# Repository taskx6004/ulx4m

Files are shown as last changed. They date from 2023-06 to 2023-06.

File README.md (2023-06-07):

<!--
SPDX-FileCopyrightText: 2016 2016 Goran Mahovlic, <goran.mahovlic@gmail.com> et al.

SPDX-License-Identifier: CERN-OHL-S-2.0
-->

# ULX4M-LS PCB

[ULX4M] = University digital Logic Learning Xtensible board release 4 Moduler successor of [ULX3S](http://radiona.org/ulx3s) = [University digital Logic](https://www.fer.unizg.hr/en/course/diglog) Learning
Xtensible board release 3 with SDRAM,
Successor of [ULX2S](http://github.com/emard/ulx2s).

### 3D preview

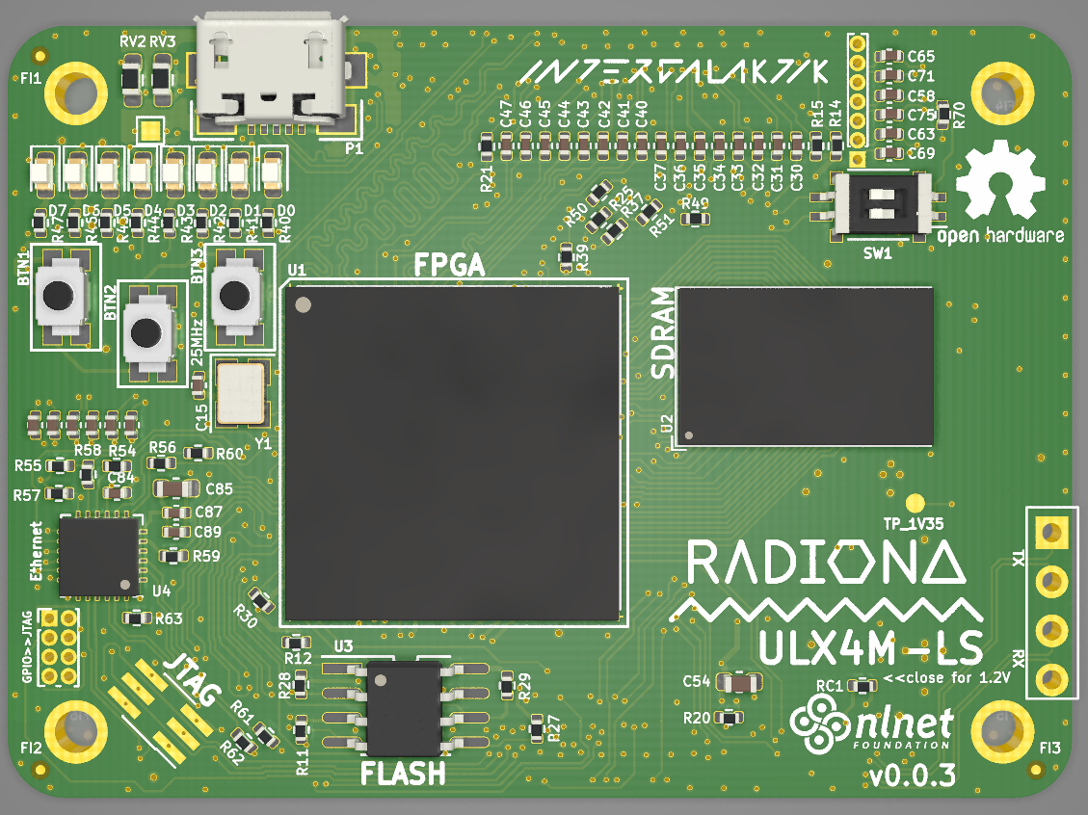
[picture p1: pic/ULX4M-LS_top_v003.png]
TOP

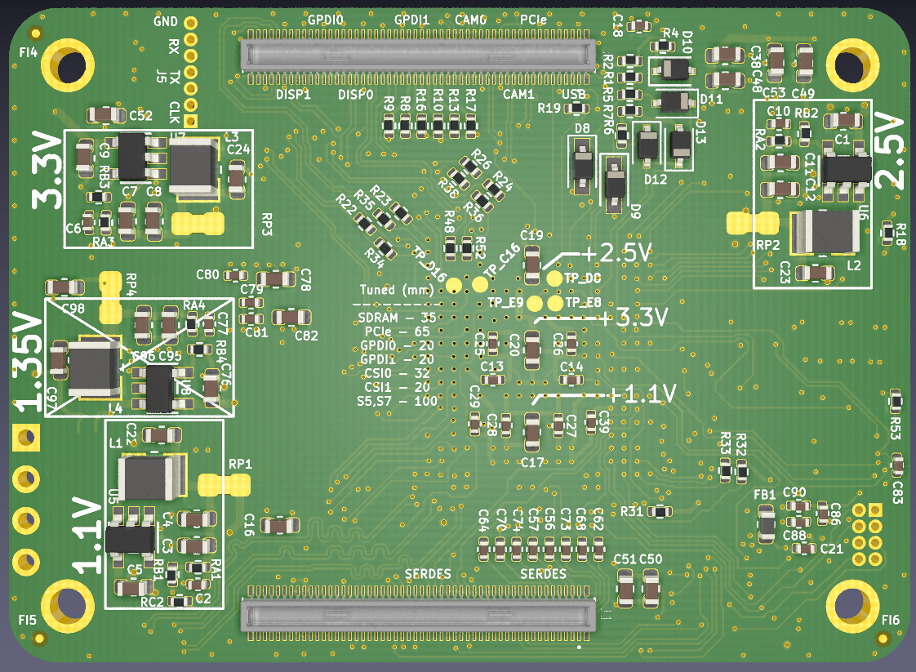
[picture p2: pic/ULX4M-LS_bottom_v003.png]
BOTTOM

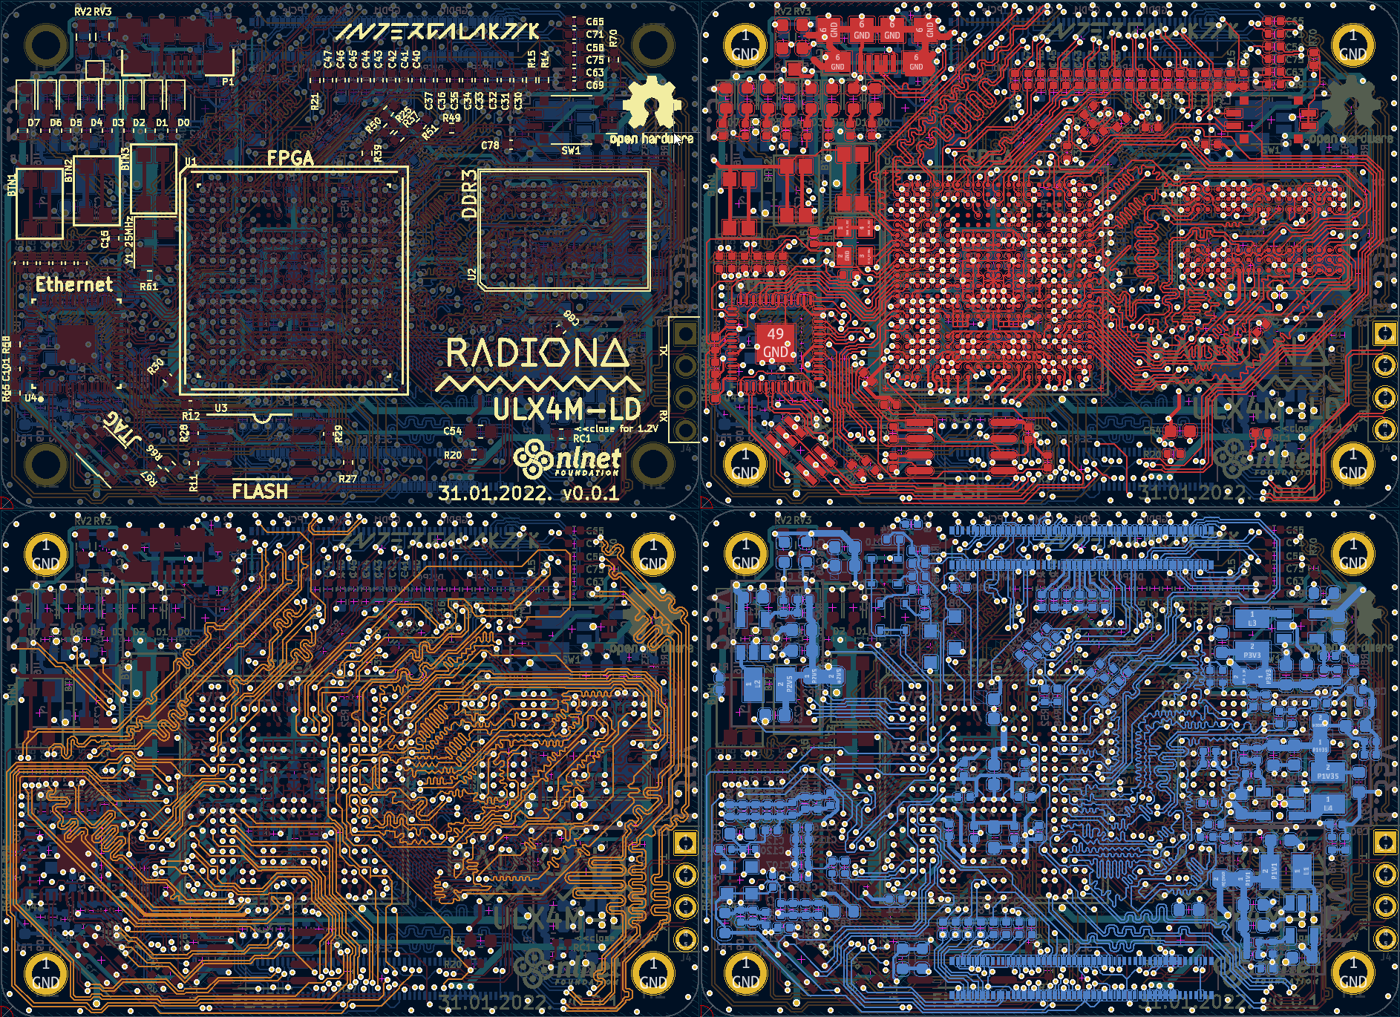
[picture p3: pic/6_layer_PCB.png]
Layers_v001


### Panel

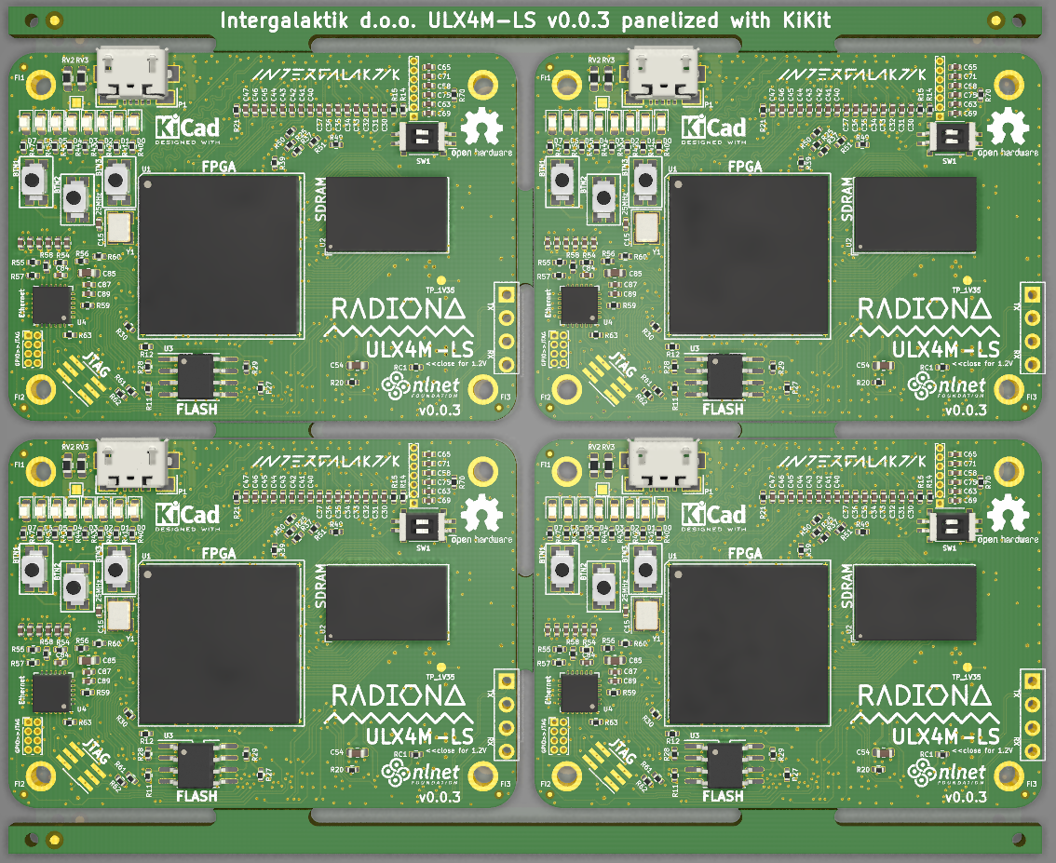
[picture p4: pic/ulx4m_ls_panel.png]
Panel


[Schematics](/doc/schematics.pdf) and PCB KiCAD 5 PCB editor:

    kicad ulx4m.pro

## Features

FPGA: Lattice ECP5 [LFE5U-12F-6BG381C](http://www.latticesemi.com/~/media/LatticeSemi/Documents/DataSheets/ECP5/FPGA-DS-02012.pdf?document_id=50461) (12/25/45/85K LUT)

### Main parts

LFE5U-12F-6BG381C

IS42S16160G-7BL 32 MB SDRAM 

W25Q128JVSIM NOR Flash spiFlash, 3V, 128M-bit, 4Kb Uniform Sector

Ethernet - LAN8720A

### Programming options

External JTAG programming connector

JTAG connected to GPIO (programming with FTDI or ESP32)

USB (bootloader)

### Periferals

- [x] 2 lane CSI camera port  CAM0 and CAM1

- [x] 2 lane DSI display port DISP0 (fake differential)

- [x] DISP0 pins connected to DISP1

- [x] * SerDes pair (TX/RX) connected to 2.0 header (radio experiments)

- [x] True differential GPDI video output

- [x] Fake differential GPDI video output

- [x] 4 bit SD card connection

- [x] * SerDes connected to PCIe 1x 

- [x] * 2x SerDes pairs connected over capacitors to connector

- [x] GPIOs

- [x] 3 Buttons

- [x] 2 DIP SW

- [x] 8 LEDs

* Only available if ECP5 SerDes chip is used

### ULX4M on TOFU carrier board

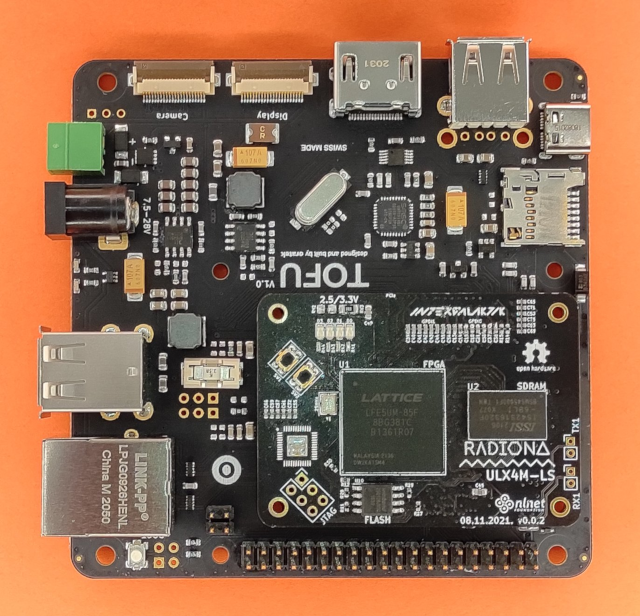
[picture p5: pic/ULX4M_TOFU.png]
TOFU


## References

https://github.com/gatecat/TrellisBoard

https://github.com/orangecrab-fpga/orangecrab-hardware

https://github.com/antmicro/ecp5-dc-scm

https://github.com/butterstick-fpga/butterstick-hardware

## Work on this board is financed by NLnet foundation

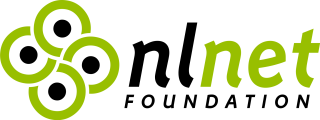
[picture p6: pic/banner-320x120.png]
NLnet


https://nlnet.nl/project/ULX3M/

## Check up our blogposts

https://intergalaktik.eu/news/ulx4s-v0-0-1

https://intergalaktik.eu/news/ulx4s-v0-0-2

https://intergalaktik.eu/news/blending-ulx4m-nlnet-funded-fpga-board

https://intergalaktik.eu/news/production-testing-automation-for-ulx3s

https://intergalaktik.eu/news/blending-ulx4m-ls-v002

## Contact us

Discord: https://discord.gg/qwMUk6W

Gitter: https://gitter.im/ulx3s/Lobby

Mail: warp@intergalaktik.eu

Twitter: https://twitter.com/intergalaktikEU

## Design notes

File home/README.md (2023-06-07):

# User's home directory config

This is copy of my home config kicad directory

    ~/.config/kicad/

It seems that newly installed kicad 5 debian
doesn't by default set all paths correctly.

Opening ulx4m project shows many schematics simbols
as question marks.

Manually copying this config to user's home config
seems to help.

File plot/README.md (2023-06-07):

# Submitting for production (panelized by manufacturer)

If manufacturer panelizes, we should create
gerber files for a single PCB.

From pcbnew open PCB, view it and menu

    File->Plot

Click "Plot" to create gerbers and click "Generate Drill File"
another window will open. Click "Drill file" to create drill files.

Generate footprint positions

    File->Fabrication Outputs->Footprint Position (.pos) File

Generate floorplan PDF for top and bottom side

    File->Print
    [x] F.Fab  [ ] Print Mirrored
    [x] B.Fab  [x] Print Mirrored

RAR or ZIP to a file

    cd plot
    rar a  /tmp/ulx4m-pcb.rar gerbers
    zip -r /tmp/ulx4m-pcb.zip gerbers

Open [Seeedstudio PCB production](https://www.seeedstudio.com/fusion_pcb.html)
page, select:

    Size: 94x51 mm
    Layer: 4-layer board
    Min Solder Mask: 0.1 mm
    Min Hole size: 0.2 mm
    Min Tracking/Spacing: 5/5 mils
    Quality: IPC Class 3

click "Add your gerber file" and upload this rar file then
click on "Gerber Viewer" to see what will be produced.

Exporting for production:

Drill file:
[x] Excellon format
[x] inch units
[x] suppress trailing zeros
[x] PTH and NPTH in the same file

Footprint position file:
[x] ASCII format
[x] mm units

# Submitting for production (panelized by us)

If we panelize, we should create gerbers for panel
and the stencil. Gerbers should have a file describing
depanelization cuts (vertical v-cuts and horizontal mill
lines).

Install [KiKit](https://github.com/yaqwsx/KiKit) (v0.7 used here) or upgrade

    pip3 install kikit
    pip3 install --upgrade kikit

Generate gerbers (needs "KiKit" installed)

    make

View panel gerbers with gerbv:

    cd plot
    gerbv (File->Open ulx4m-panel.gvp, F5 to refresh)

View panel design with pcbnew (try View->3D Viewer):

    pcbnew plot/panel/ulx4m-panel.kicad_pcb

Compress with rar (should fit max size 10 MB)

    cd plot/panel
    rar a /tmp/ulx4m-panel-gerber.rar ulx4m-panel-gerber

Upload .rar file to [JLCPCB](http://jlcpcb.com) and select options:

    PCB Panel
    -------------------
    Base Material       : [FR-4] Aluminium
    Layers              : 1  2 [4] 6
    Dimensions [mm]     : 224 * 264
    PCB Qty             : 5 [10] 15  20
    Different Design    : [1] 2  3  4
    Delivery Format     : Single PCB [Panel by Customer] Panel by JLCPCB
    Panel Format        : Columns: 2  Rows: 4
    PCB Thickness       : 0.8  1.0  1.2 [1.6] 2.0 mm
    Impedance           : [No] Yes
    PCB Color           : [Green] Red Yellow Blue White Black
    Silkscreen          : White
    Surface Finish      : HASL(with lead) LeadFree HASL-RoHS [ENIG-RoHS]
    Outer Copper Weight : [1 oz] 2 oz
    Inner Copper Weight : [0.5 oz] 2 oz
    Gold Fingers        : [No] Yes
    Material Type       : FR4-Standard Tg 130-145C [FR4 TG155] 
    Confirm Production file : No [Yes]
    Flying Probe Test   : [Fully Test] Not Test
    Castellated Holes   : [No] Yes
    Remove Order Number : [No] Yes  Specify Location

    Advanced options
    Min Hole            : 0.45 mm [0.2/0.4 mm]
    4-Wire Kelvin Test  : No [Yes]
    Paper between PCBs  : No [Yes]
    Appearance Quality  : [IPC Class 2 Standard] Superb Quality

    PCB Remark:         : 4 vertical V-CUTS, 16 horizontal MILL LINES of 2 mm width
                          Use external edges from "EdgeCuts.gbr" layer
                          Ignore internal edges from "EdgeCuts.gbr" layer

    SMT Assembly        : No

    Stencil             : Yes (Order together with PCB)
    -------------------
    Framework           : No [Yes]
    Dimensions [mm]     : 470*370 (valid area 290*190)
                          400*300 (valid area 240*140)
                         [520*420 (valid area 340*240)]
    Customized size     : [No] Yes
    Stencil Side        : Top+Bottom (On Single Stencil)
                          Top
                          Bottom 
                         [Top&Bottom (On Separate Stencil)]
    Electropolishing    : No [Yes]
    Fiducials           : No Fiducial
                          Etched Through
                         [Etched Half into board]

    Sending options     : EuroPacket

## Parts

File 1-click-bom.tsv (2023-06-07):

References | Qty | Description | Manufacturer | MPN | Manufacturer | MPN | Manufacturer | MPN | Manufacturer | MPN | Digikey | Mouser | RS | Newark | Farnell | LCSC | JLC Assembly
C2, C6, C10 | 3 | 100pF |  | 04026C101KAT2A | AVX | 04026C101KAT2A |  |  |  |  | 478-12647-6-ND | 58104026C101KAT2A
C25, C26, C27, C28, C29, C30, C31, C32, C33, C34, C35, C55, C56, C57, C58, C59, C61, C62, C63, C64, C65, C66, C67, C68, C69, C70, C71, C72, C73, C74, C75 | 31 | 22nF |  | 04023D223KAT2A | KYOCERA AVX | 04023D223KAT2A |  |  |  |  | 478-10083-1-ND | 58104023D223KAT2A |  |  | 3288826
C48, C49, C50, C51, C52, C53 | 6 | 22nF |  | 06033D223KAT2A | KYOCERA AVX | 06033D223KAT2A |  |  |  |  | 478-06033D223KAT2ATR-ND | 58106033D223KAT2A
C13, C14, C15, C18, C21, C36, C37, C38, C39, C40, C41, C42, C43, C44, C45, C54 | 16 | 100n |  | 0402YD104KAT2A | AVX | 0402YD104KAT2A |  |  |  |  | 478-1126-1-ND | 5810402YD104K | 6983197 |  | 1327666
C60 | 1 | 220nF |  | CGB2T3X5R0J224M022BB | TDK | CGB2T3X5R0J224M022BB |  |  |  |  | 445-15613-1-ND | 810CGB2T3X5R0J224MB
C16, C17, C19, C20, C22, C23, C24, C46, C47 | 9 | 2.2uF |  | 06033D225KAT2A | AVX | 06033D225KAT2A |  |  |  |  |  | 58106033D225KAT2A
C1, C3, C4, C5, C7, C8, C9, C11, C12 | 9 | 22uF |  | C0603C226M9PACTU | KEMET | C0603C226M9PACTU |  |  |  |  |  | 80C0603C226M9PACTU |  |  | 3754565
RV3 | 1 | 0 |  | RC0805JR-070RL | Yageo | RC0805JR-070RL | Yageo | RC0805JR-070RP | Vishay | RCG08050000Z0EA | 311-0.0ARCT-ND | 603RC0805JR070RL | 1995753 |  | 1799478
R1, R2 | 2 | 27 |  | RC0402FR-0727RL | Yageo | RC0402FR-0727RL |  |  |  |  | YAG3086DKR-ND | 603RC0402FR0727RL |  |  | 9239049
R18 | 1 | 130 |  | RC0402FR-07130RL | Yageo | RC0402FR-07130RL |  |  |  |  | 311-130LRDKR-ND | 603RC0402FR07130RL |  |  | 3495526
R41, R42, R43, R44 | 4 | 549 |  | RT0402BRD07549RL | Yageo | RT0402BRD07549RL |  |  |  |  | YAG4280DKR-ND | 603RT0402BRD07549RL
R29, R4, R6 | 3 | 1.1k |  | RC0402JR-071K1L | Yageo | RC0402JR-071K1L |  |  |  |  | 311-1.1KJRCT-ND | 603RC0402JR071K1L
RB3 | 1 | 3.3k |  | RC0402FR-073K3L | Yageo | RC0402FR-073K3L |  |  |  |  | 311-3.30KLRCT-ND | 603RC0402FR073K3L | 1987781 |  | 2693607
R3, R30, RB2, R10, R13, R14, R15, R19, R20 | 9 | 4.7k |  | RC0402JR-074K7L | Yageo | RC0402JR-074K7L |  |  |  |  | 311-4.7KJRCT-ND | 603RC0402JR074K7L | 1987981 |  | 9232842
R11, R12, R27, R28 | 4 | 10k |  | CRCW040210K0FKTD | Vishay | CRCW040210K0FKTD |  |  |  |  | 541-2955-6-ND | 71CRCW040210K |  |  | 1652741RL
R31, R32, R33, RA1, RA2, RA3, R5, R7 | 8 | 15k |  | RMCF0402FT15K0 | Stackpole Electronics | RMCF0402FT15K0 |  |  |  |  | RMCF0402FT15K0CT-ND
RB1 | 1 | 18k |  | RC0402FR-0718KL | Yageo | RC0402FR-0718KL |  |  |  |  | 311-18.0KLRCT-ND | 603RC0402FR0718KL | 1987675 |  | 9239383
R8, R9, R16, R17 | 4 | 100k |  | RMCF0402JT100K | Stackpole Electronics | RMCF0402JT100K |  |  |  |  | RMCF0402JT100KDKR-ND
L1, L2, L3 | 3 | 2.2uH |  | DFE322512F-2R2M=P2 | Murata | DFE322512F-2R2M=P2 | TDK | TFM322512ALMA2R2MTAA |  |  | 445-TFM322512ALMA2R2MTAADKR-ND | 81DFE322512F2R2MP2 |  | 57AC6667 | 3490850 | C285758
D4, D5, D6, D7, D17, D28, D29 | 7 | 1N914 |  | 1N4148WS | Diotec | 1N4148WS | onsemi | 1N914BWS | Nexperia | BAS316Z | 1N914BWSDKR-ND | 5121N914BWS |  |  | 2453274RL
D8, D9 | 2 | 3.6V |  | BZT52C3V6S | Rectron | BZT52C3V6S | MCC | BZT52C3V6S-TP |  |  | BZT52C3V6S-TPMSCT-ND | 833BZT52C3V6STP
D0 | 1 | GREEN |  | LTST-C190GKT | Lite-On | LTST-C190GKT |  |  |  |  | 160-1183-2-ND | 859LTSTC190GKT | 6920975P
D1 | 1 | BLUE |  | LTST-C190TBKT | Lite-On | LTST-C190TBKT |  |  |  |  | 160-1646-1-ND | 859LTSTC190TBKT | 6920994P
D2 | 1 | GREEN |  | LTST-C190GKT | Lite-On | LTST-C190GKT |  |  |  |  | 160-1183-2-ND | 859LTSTC190GKT | 6920975P
D3 | 1 | BLUE |  | LTST-C190TBKT | Lite-On | LTST-C190TBKT |  |  |  |  | 160-1646-1-ND | 859LTSTC190TBKT | 6920994P
U1 | 1 | LFE5UM-85F-8BG381I |  | LFE5UM-85F-8BG381I | Lattice Semiconductor | LFE5UM-85F-8BG381I |  |  |  |  | LFE5UM-85F-8BG381I-ND | 842LFE5UM85F8BG381I
U2 | 1 | IS42S16320D-6BLI |  | IS42S16320D-6BLI | ISSI | IS42S16320D-6BLI |  |  |  |  | IS42S16320D-6BLI-ND | 870IS42S16320D6BLI
U3, U4, U5 | 3 | TLV62569DBV |  | TLV62569DBVR | Texas Instruments | TLV62569DBVR |  |  |  |  | 296-47360-2-ND | 595TLV62569DBVR |  |  | 3121687
U10 | 1 | W25Q128JVSIM |  | W25Q128JVSIM | Winbond | W25Q128JVSIM |  |  |  |  | W25Q128JVSIM-ND | 454W25Q128JVSIM | 1882648P
Y1 | 1 | FO3HSCBE25.0-T1 |  | FO3HSCBE25.0-T1 | Fox Electronics | FO3HSCBE25.0-T1 |  |  |  |  | 631-1432-1-ND | ASE25.000MHZLCT
SW1, SW2 | 2 | SW_Push |  | R-667903 | Mitsumi | R-667903 |  |  |  |  | 2508-R-667903CT-ND
J1, J2 | 2 | DF40C-100DP-0.4V(51) |  | 798-DF40C100DP0.4V51 | Hirose | DF40C-100DP-0.4V(51) |  |  |  |  | H11614DKR-ND | 798DF40C100DP0.4V51 |  |  | 2427678

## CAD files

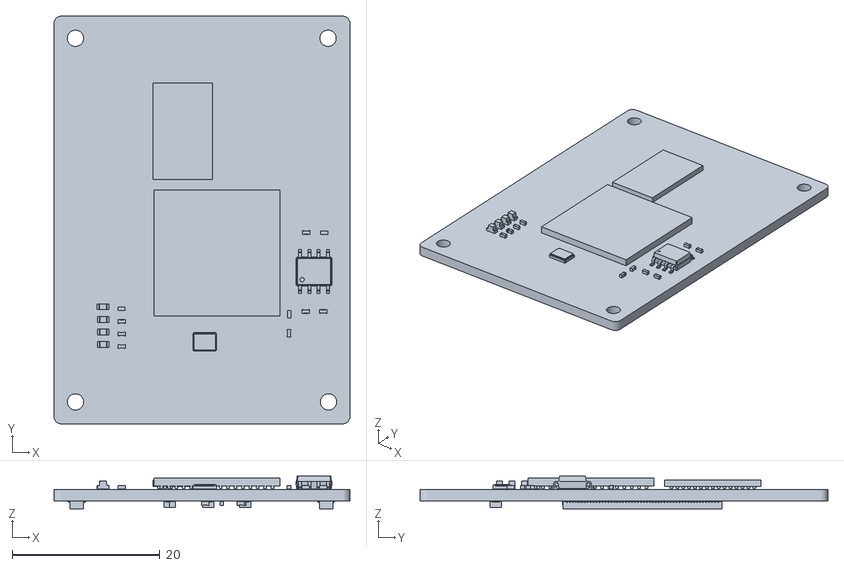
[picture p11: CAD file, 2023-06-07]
experimental/3D/ULX4M.stl
40.0 x 55.1 x 4.44

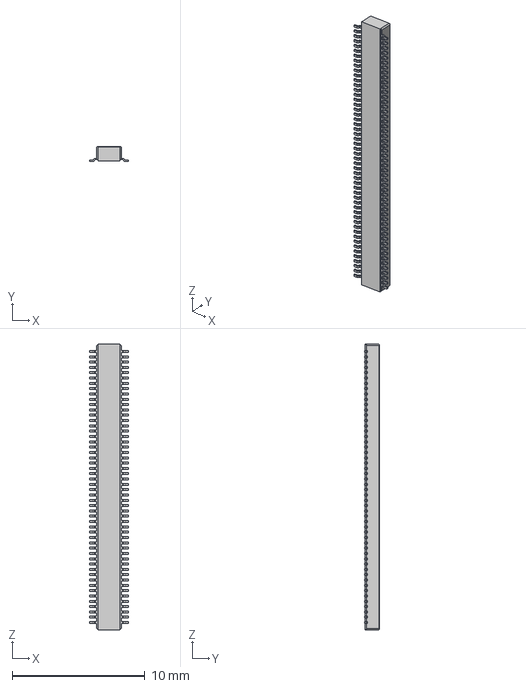
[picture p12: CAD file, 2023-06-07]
footprints/connectors/3D/DF40C-100DP.stp
2.97 x 1.14 x 21.5 mm

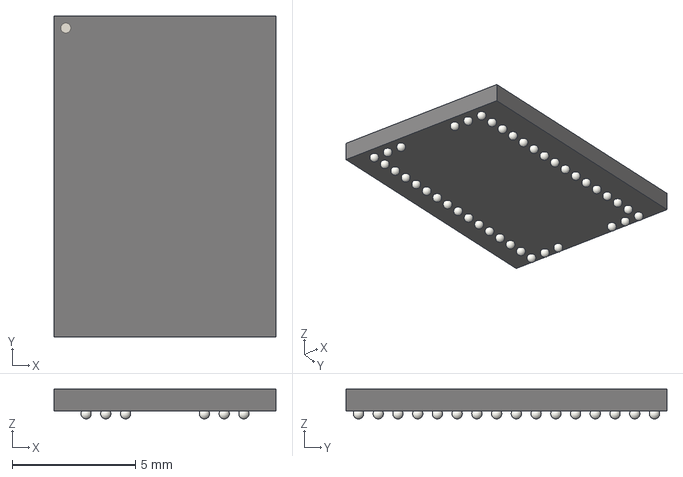
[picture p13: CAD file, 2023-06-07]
footprints/ddr3/AS4C256M16D3/3D/BGA-96_9.0x13.0mm_Layout2x3x16_P0.8mm.step
9.00 x 13.0 x 1.21 mm

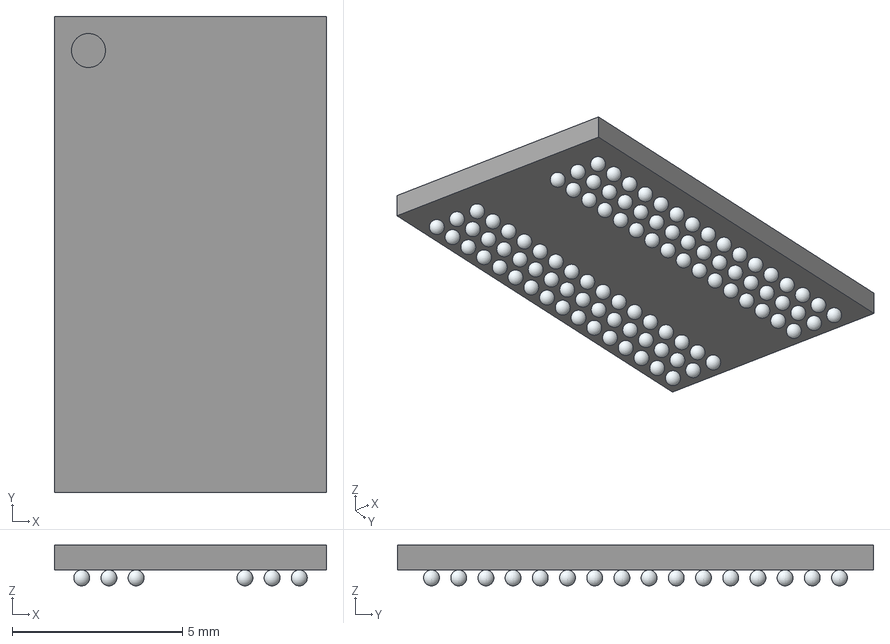
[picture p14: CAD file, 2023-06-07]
footprints/ddr3/MT41K256M16TW-107_P/3D/MT41K256M16TW-107_P.stp
8.00 x 14.0 x 1.20 mm
A1
A2
A3
A7
A8
A9
B1
B2
B3
B7
B8
B9
C1
C2
C3
C7
C8
C9
D1
D2
D3
D7
D8
D9
E1
E2
E3
E7
E8
E9
F1
F2
F3
F7
F8
F9
G1
G2
G3
G7
G8
G9
H1
H2
H3
H7
H8
H9
J1
J2
J3
J7
J8
J9
K1
K2
K3
K7
K8
K9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

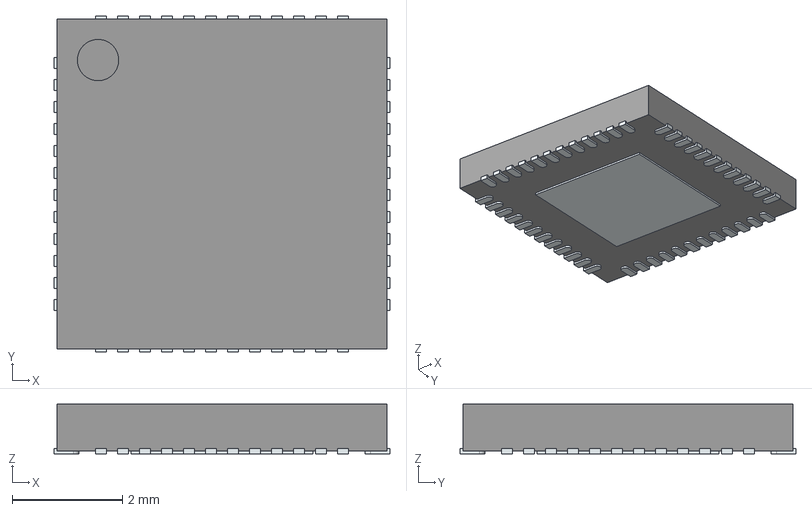
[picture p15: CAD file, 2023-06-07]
footprints/network/VSC8530XMW-04/3D/VSC8530XMW-04.stp
6.10 x 6.10 x 0.9 mm
ThermalPin
PinsArrayLR
PinsArrayTB

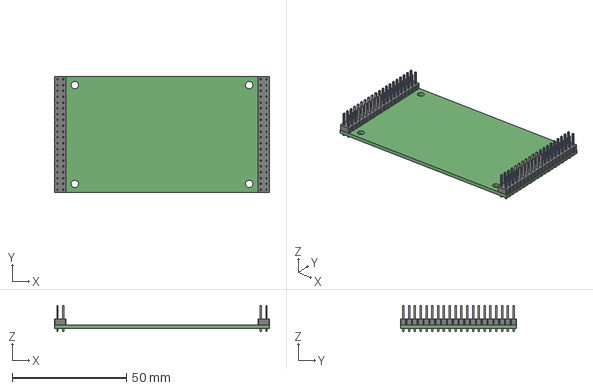
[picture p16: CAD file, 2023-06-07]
ulx4m_bare.step
94.0 x 50.8 x 11.5 mm

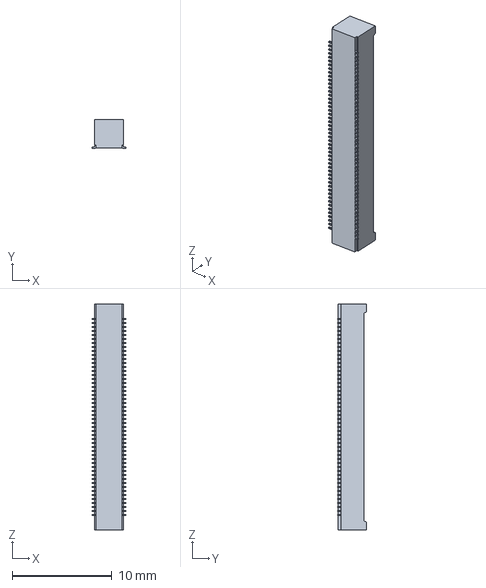
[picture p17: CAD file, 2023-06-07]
footprints/connectors/3D/DF40HC(3.0)-100DS-0.4V.stp
3.38 x 2.90 x 22.6 mm

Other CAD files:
footprints/network/VSC8530XMW-04/3D/VSC8530XMW-04.stl

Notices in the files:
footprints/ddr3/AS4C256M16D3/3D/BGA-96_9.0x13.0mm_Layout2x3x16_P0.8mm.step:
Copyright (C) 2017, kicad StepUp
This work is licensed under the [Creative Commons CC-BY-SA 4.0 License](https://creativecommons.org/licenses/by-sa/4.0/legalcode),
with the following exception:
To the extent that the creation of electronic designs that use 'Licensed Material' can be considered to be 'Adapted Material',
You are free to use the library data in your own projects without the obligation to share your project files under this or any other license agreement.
